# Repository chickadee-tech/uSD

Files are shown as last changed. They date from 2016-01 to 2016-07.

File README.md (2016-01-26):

# Chickadee Tech MicroSD Polystack Mod #
This mod adds a microSD card to a Polystack.

## Documentation ##
See the [wiki](https://github.com/chickadee-tech/uSD/wiki) for documentation.

## Polystack ##
This **mod** board is part of the Polystack platform for modular microcontrol systems. More information on the platform can be found at [polystack.org](http://polystack.org).

## Support ##
If you need support with a board you own or have development questions please email support@chickadee.tech or check [chickadee.tech/support](https://chickadee.tech/support) for other ways to get support.

## Contributing ##
Please note that this project is released with a [Contributor Code of Conduct](CODE_OF_CONDUCT.md). By participating in this project you agree to abide by its terms.

### Setup ###
Components and footprints for PCB parts are not included in this repository. Instead, checkout the [chickadee-tech/kicad-libs](https://github.com/chickadee-tech/kicad-libs) repository in the same directory that this repository is checked out in. All part definitions should be relative so that they will load correctly.

### Pull requests ###
For fixes please submit a pull request to the original repository. After the pull request is merged, check the [Chickadee Tech Active Contributor Discount (ACD)](https://chickadee.tech/active-contributor) to see if you are eligible for a discount code to use on your next purchase.

### Derivatives ###
If developing your own version of the MicroSD board please remove all Chickadee Tech trademarks and follow the [CC-BY license](LICENSE). While not required, please consider open sourcing your modifications so others can learn from your improvements. If you do email support@chickadee.tech and we may choose to add your project to the ACD.

You may also license the Polystack logo for free by emailing support@chickadee.tech. We'll ask for your gerbers to ensure the design complies with specifications laid out [here](https://github.com/chickadee-tech/polystack/wiki) and provide written permission to use the trademark after compliance has been demonstrated.

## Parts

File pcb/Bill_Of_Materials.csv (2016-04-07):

part name | symbol | size (imp) | max current | unit price | units per build | units in stock | order total | Manufacturer ID | source url | datasheet | datasheet2
80 pin header | PORT_IN1 |  |  | $1.35 | 1 | 1 | $1.35 | DF40C-80DP-0.4V(51) | http://www.digikey.com/product-detail/en/DF40C-80DP-0.4V(51)/H11632CT-ND/1969511 | N | http://www.hirose.co.jp/cataloge_hp/ed_DF40_20140305.pdf | Total Base Cost | $9.24
80 pin receptacle (3.5mm) | PORT_OUT1 |  | 0.3A a pin | $2.42 | 1 | 1 | $2.42 | DF40HC(3.5)-80DS-0.4V(51) | http://www.digikey.com/product-detail/en/DF40HC(3.5)-80DS-0.4V(51)/H11997CT-ND/2880228 | N | http://www.hirose.co.jp/cataloge_hp/ed_DF40_20140305.pdf
AND/OR gate | PORT_ANDOR1 |  |  | $0.25 | 1 | 2 | $0.25 | SN74LVC1G0832DCKR | http://www.digikey.com/product-detail/en/SN74LVC1G0832DCKR/296-18754-1-ND/863884 |  | http://www.ti.com/lit/ds/symlink/sn74lvc1g0832.pdf
multifunction gate | PORT_XOR1, PORT_INV1 |  |  | $0.14 | 2 | 6 | $0.28 | SN74LVC1G58DCKR | http://www.digikey.com/product-detail/en/SN74LVC1G58DCKR/296-15577-1-ND/571153 |  | http://www.ti.com/lit/ds/symlink/sn74lvc1g58.pdf
64kbit eeprom | PORT_IC1 | udfn |  | $0.61 | 1 | 2 | $0.61 | AT24CS64-MAHM-T | http://www.digikey.com/product-detail/en/AT24CS64-MAHM-T/AT24CS64-MAHM-TCT-ND/4292118 | N | http://www.atmel.com/images/atmel-8870-seeprom-at24cs64-datasheet.pdf
R 10k | PORT_R1, R3 | 603 |  | $0.01 | 2 | 979 | $0.02 | RC0603FR-0710KL | http://www.digikey.com/product-detail/en/RC0603FR-0710KL/311-10.0KHRCT-ND/729827 | MF-RES-0603-10K | http://www.yageo.com/NewPortal/yageodocoutput?fileName=/pdf/R-Chip/PYu-RC_Group_51_RoHS_L_3.pdf
C 0.1uF | PORT_C1 | 603 |  | $0.02 | 1 | 400 | $0.02 | C0603C104K4RACTU | http://www.digikey.com/product-detail/en/C0603C104K4RACTU/399-1096-1-ND/411371 | MF-CAP-0603-0.1uF | http://www.kemet.com/docfinder?Partnumber=C0603C104K4RACTU
R 1k | R1, R2 | 603 |  | $0.01 | 2 | 993 | $0.02 | RC0603FR-071KL | http://www.digikey.com/product-detail/en/RC0603FR-071KL/311-1.00KHRCT-ND/729790 | MF-RES-0603-1K | http://www.yageo.com/NewPortal/yageodocoutput?fileName=/pdf/R-Chip/PYu-RC_Group_51_RoHS_L_3.pdf
red led | D1 |  |  | $0.19 | 1 | 71 | $0.19 | LTST-C190KRKT | http://www.digikey.com/product-detail/en/LTST-C190KRKT/160-1436-1-ND/386816 | MF-LED-0603-RED | http://optoelectronics.liteon.com/upload/download/DS-22-99-0151/S_110_LTST-C190KRKT.pdf
green led | D2 |  |  | $0.19 | 1 | 83 | $0.19 | LTST-C190KGKT | http://www.digikey.com/product-detail/en/LTST-C190KGKT/160-1435-1-ND/386814 | Y | http://optoelectronics.liteon.com/upload/download/DS22-2000-074/S_110_LTST-C190KGKT.pdf
3.3v regulator | U1 | SOT23-5 | 0.3A | $0.49 | 1 | 8 | $0.49 | TLV70233DBVR | http://www.digikey.com/product-detail/en/TLV70233DBVR/296-32415-1-ND/3505572 | MF-REG-SOT235-3.3V-300mA | http://www.ti.com/lit/ds/symlink/tlv702.pdf
autoeject microsd | U2 |  |  | $2.72 | 1 | 1 | $2.72 | DM3AT-SF-PEJM5 | http://www.digikey.com/product-detail/en/DM3AT-SF-PEJM5/HR1964CT-ND/2533566 | N | http://www.hirose.co.jp/cataloge_hp/e60900232.pdf
C 10uF X5R | C1 | 1206 |  | $0.24 | 1 | 80 | $0.24 | C3216X5R1C106M160AA | http://www.digikey.com/product-detail/en/C3216X5R1C106M160AA/445-1426-1-ND/569092 | MF-CAP-1206-10uF | http://product.tdk.com/en/catalog/datasheets/mlcc_commercial_general_en.pdf
C 1uF X7R | C2 | 603 |  | $0.03 | 1 | 20 | $0.03 | TMK107B7105KA-T | http://www.digikey.com/product-detail/en/TMK107B7105KA-T/587-2984-1-ND/2714177 | MF-CAP-0603-1uF | http://ds.yuden.co.jp/TYCOMPAS/ut/detail.do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
~3.5mm Spacer | Off Board |  |  | $0.08 | 5 | 81 | $0.42 | 908-140 | http://www.mouser.com/search/ProductDetail.aspx?R=0virtualkey0virtualkey908-140 | N | http://www.bivar.com/Portals/0/Products/d.ashx?f=/Portals/0/products/9XX-XXX.pdf

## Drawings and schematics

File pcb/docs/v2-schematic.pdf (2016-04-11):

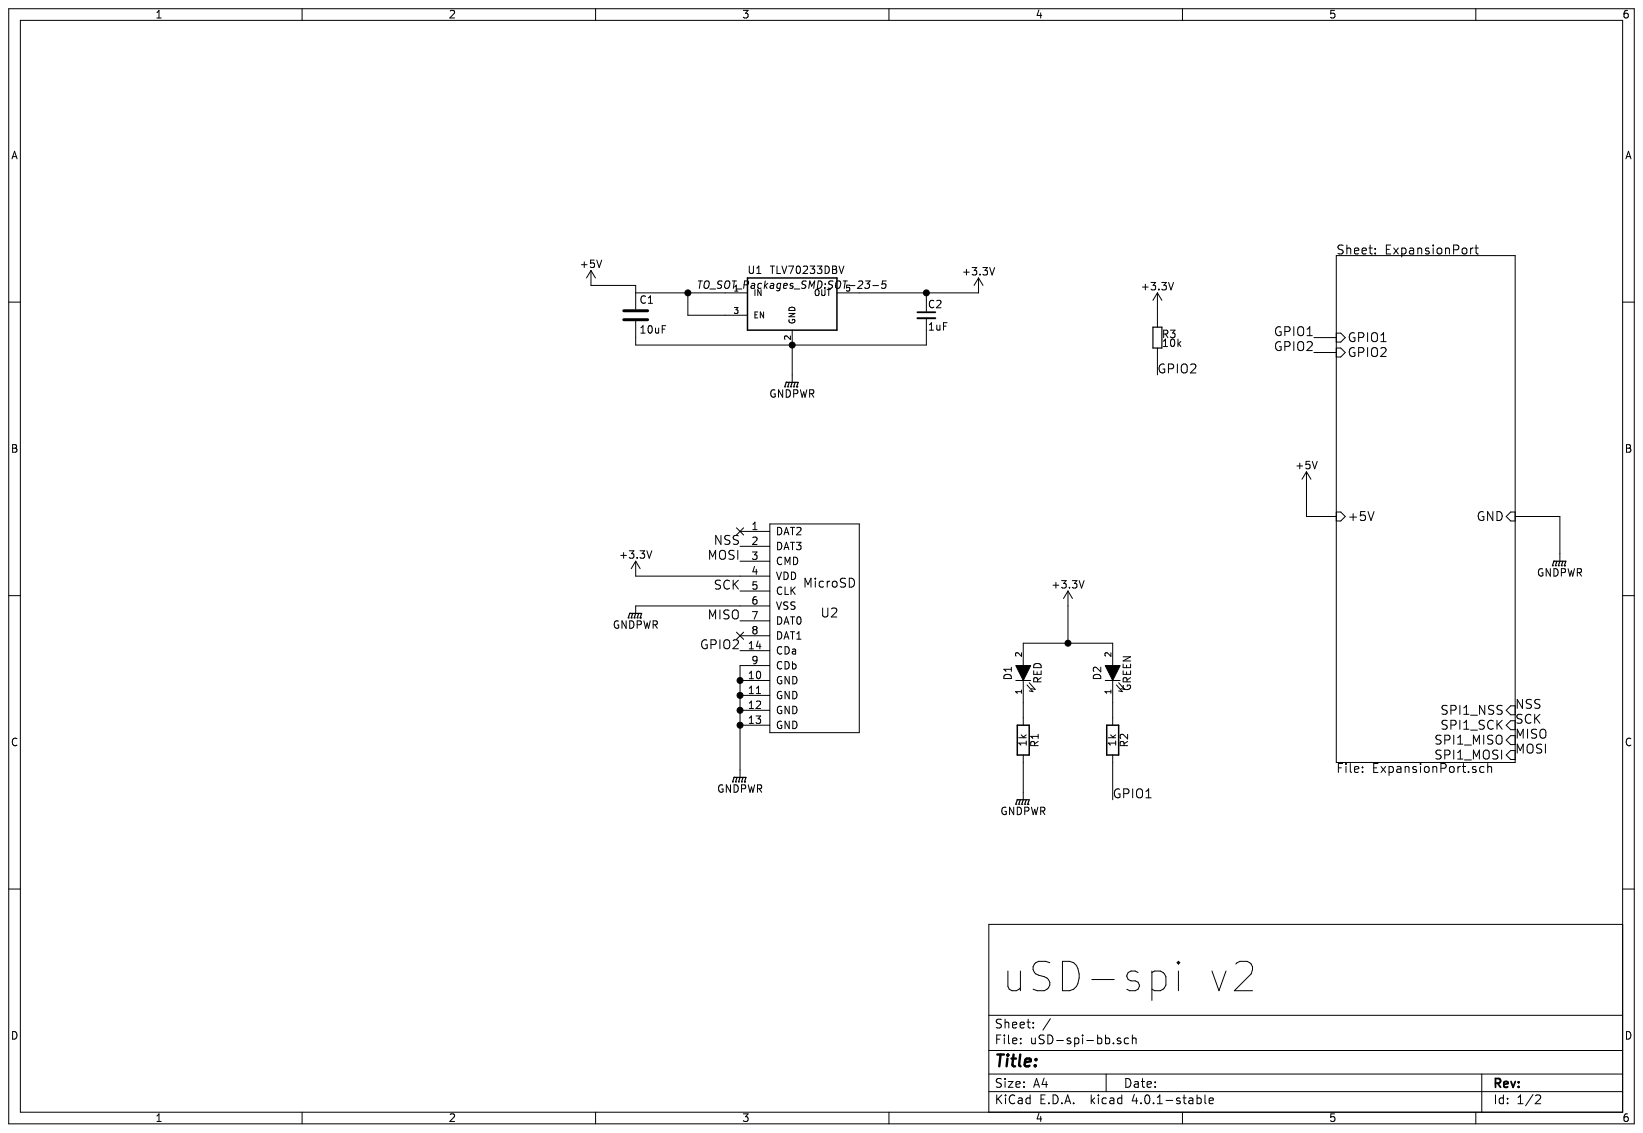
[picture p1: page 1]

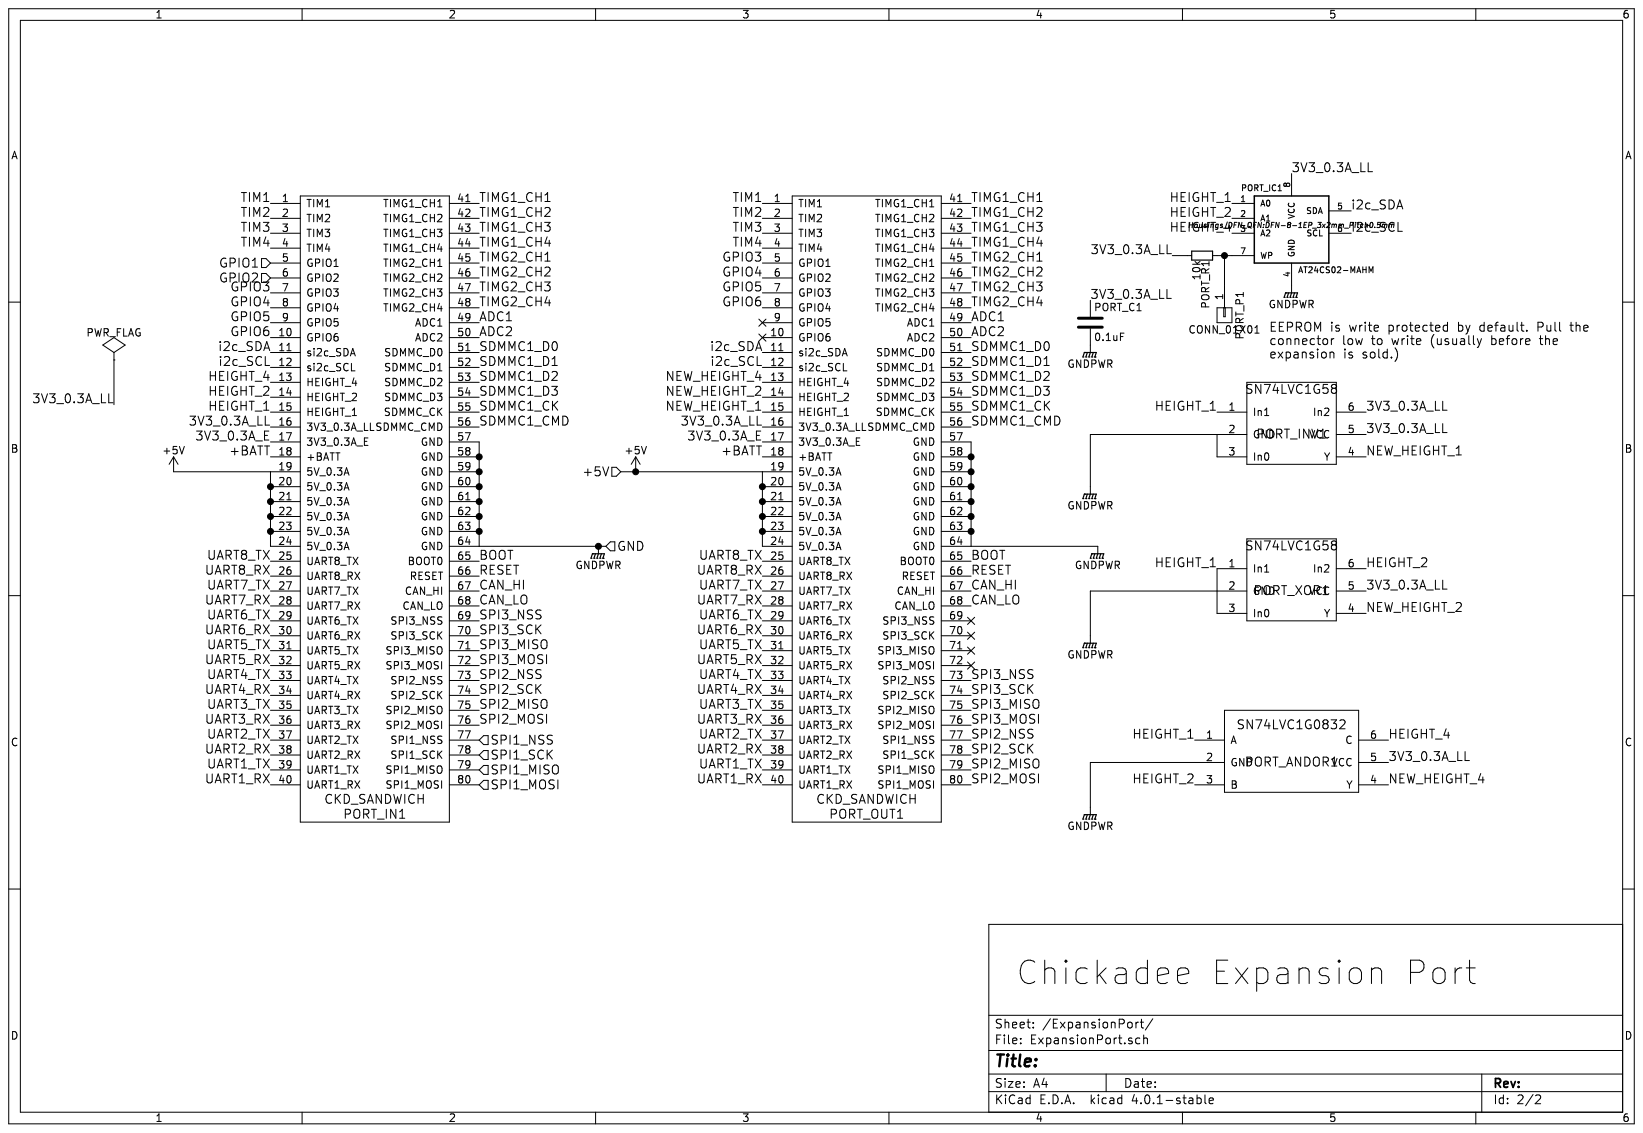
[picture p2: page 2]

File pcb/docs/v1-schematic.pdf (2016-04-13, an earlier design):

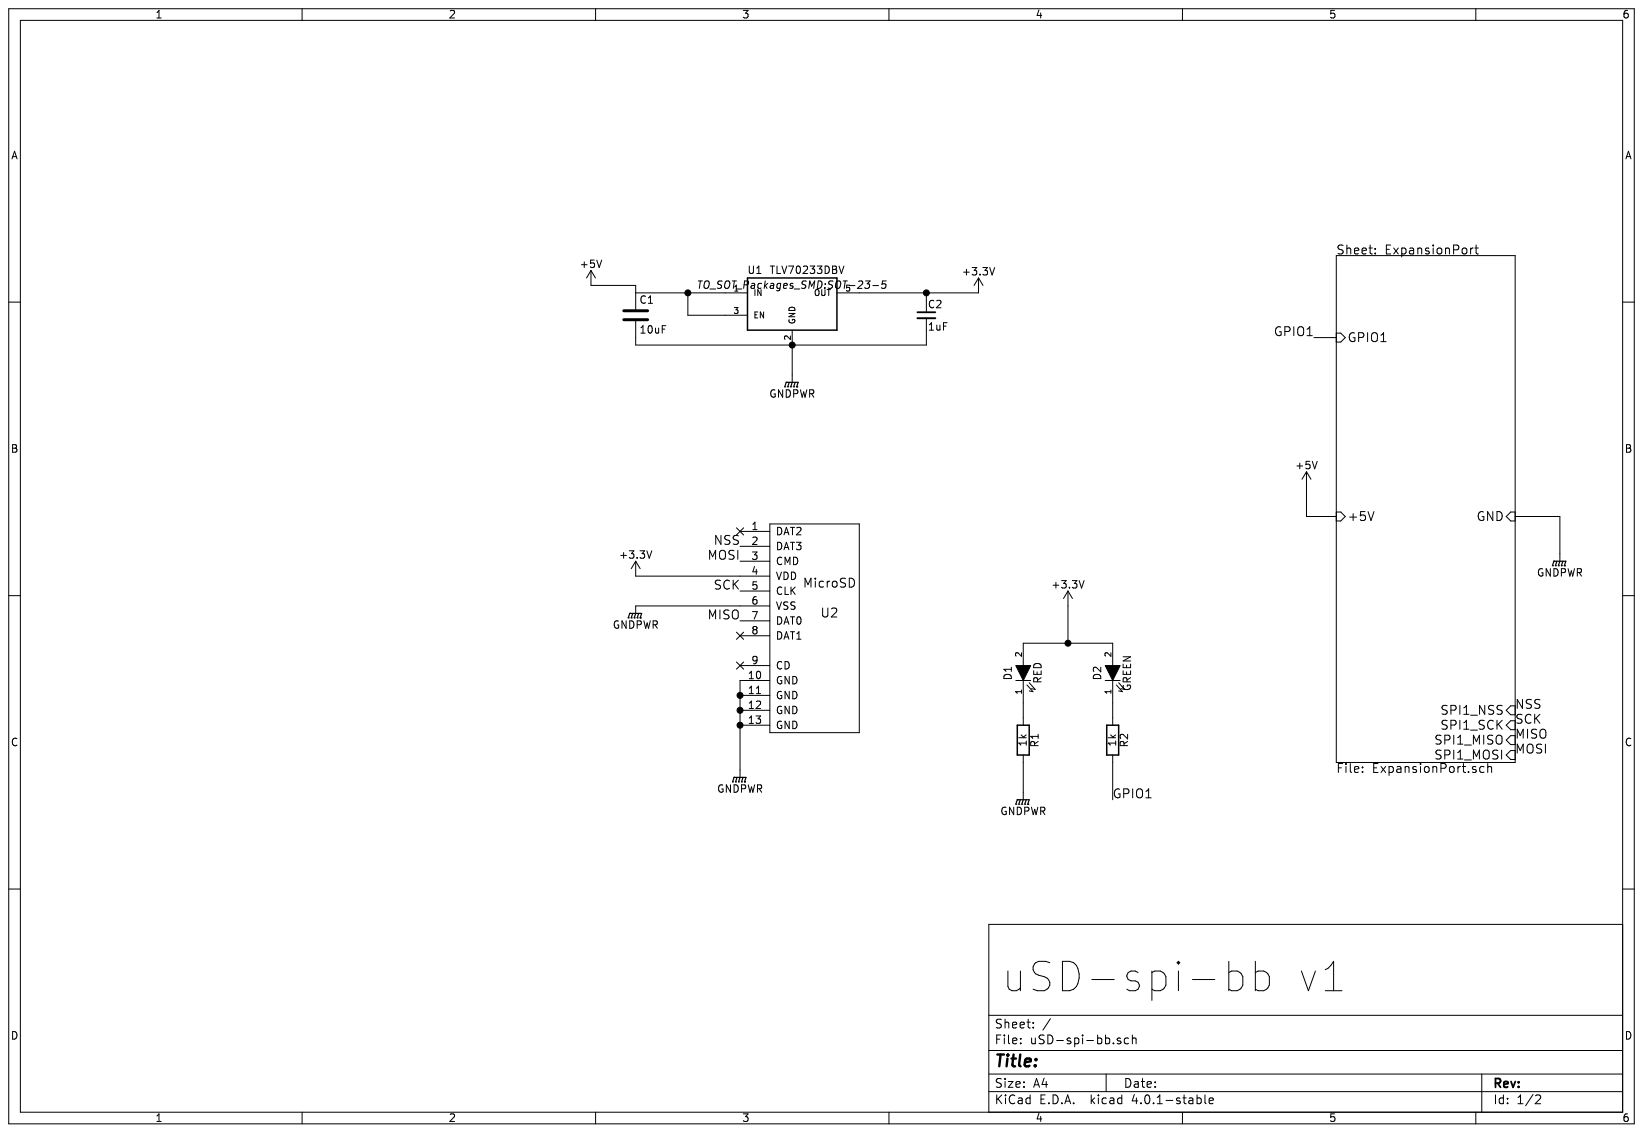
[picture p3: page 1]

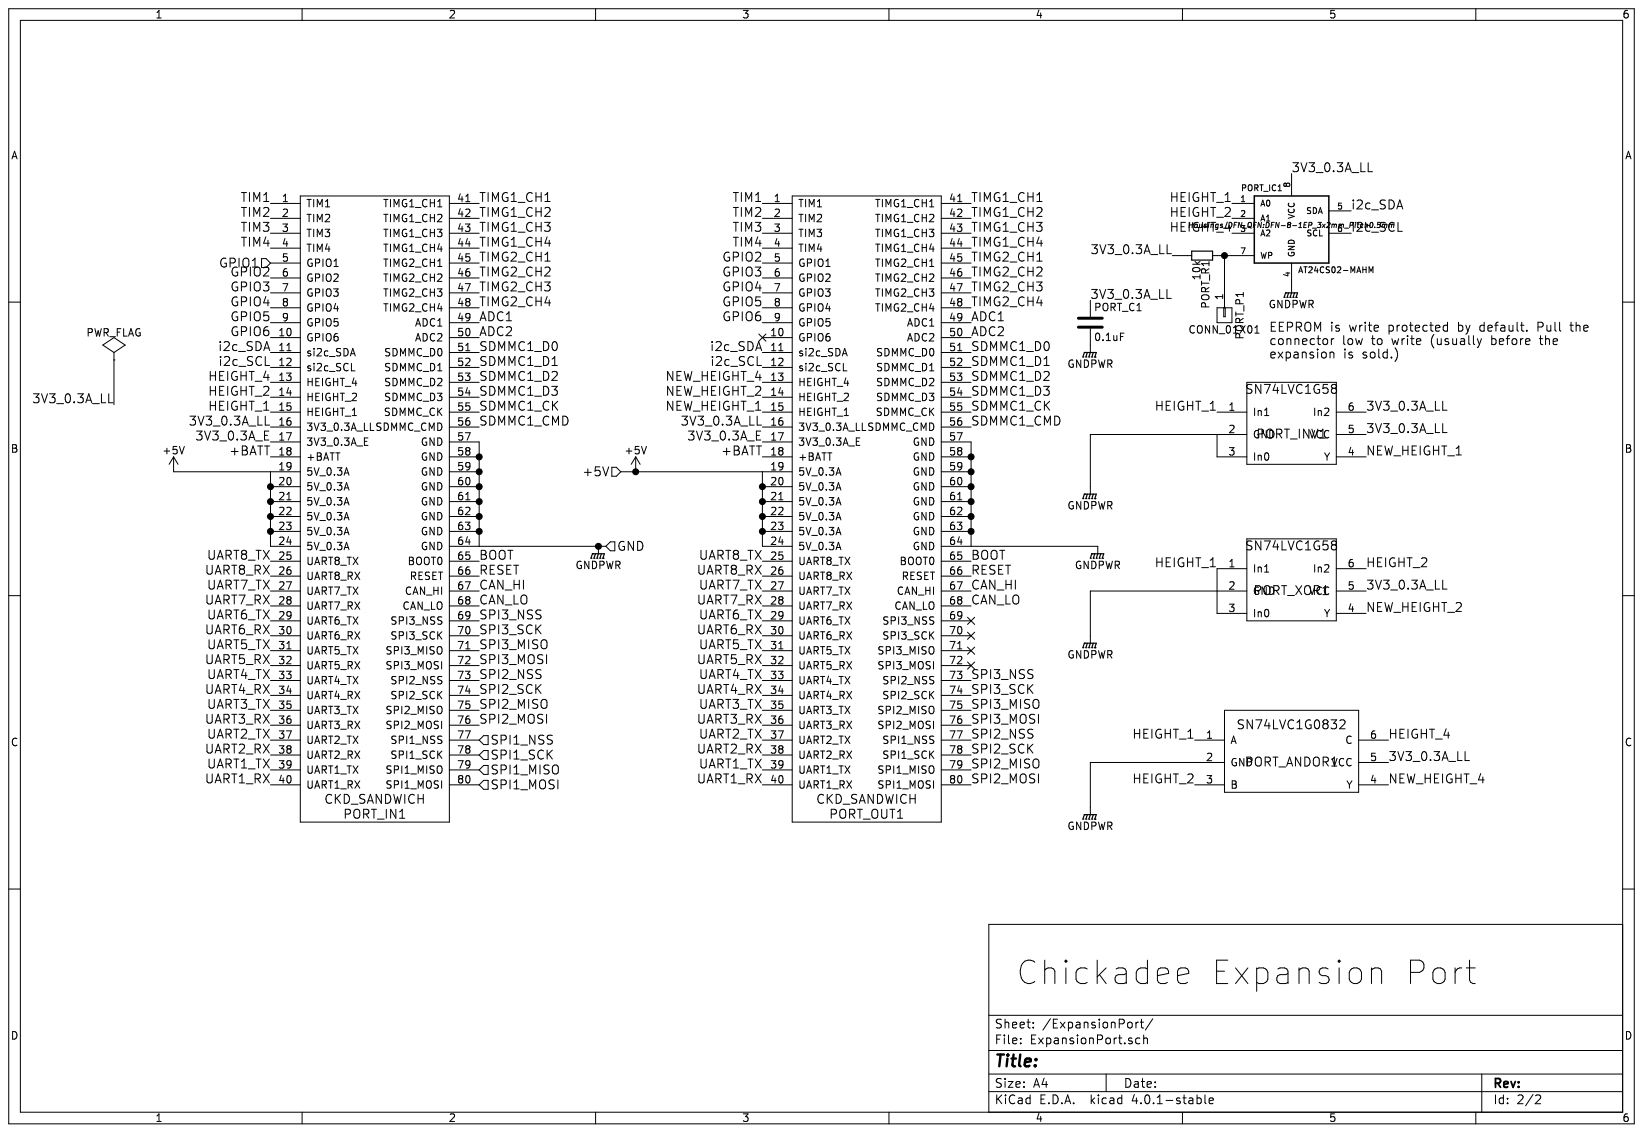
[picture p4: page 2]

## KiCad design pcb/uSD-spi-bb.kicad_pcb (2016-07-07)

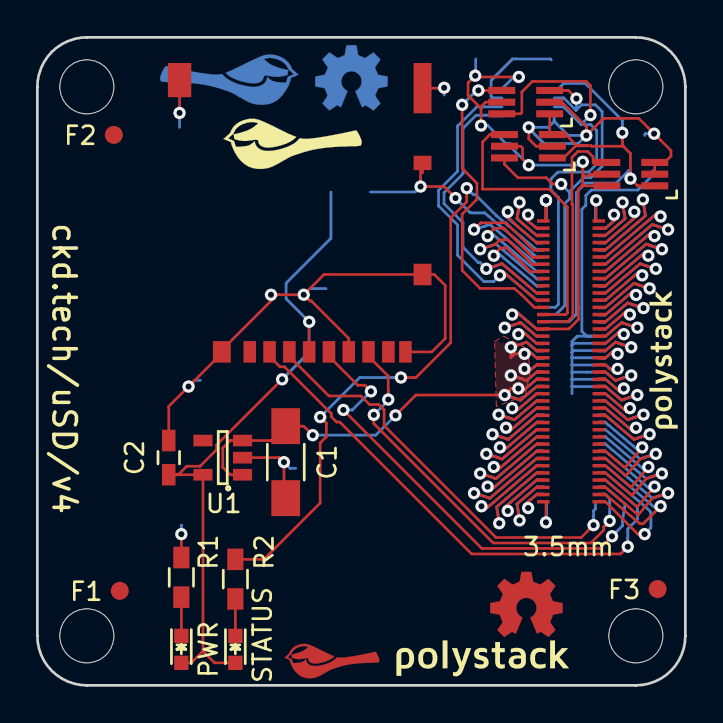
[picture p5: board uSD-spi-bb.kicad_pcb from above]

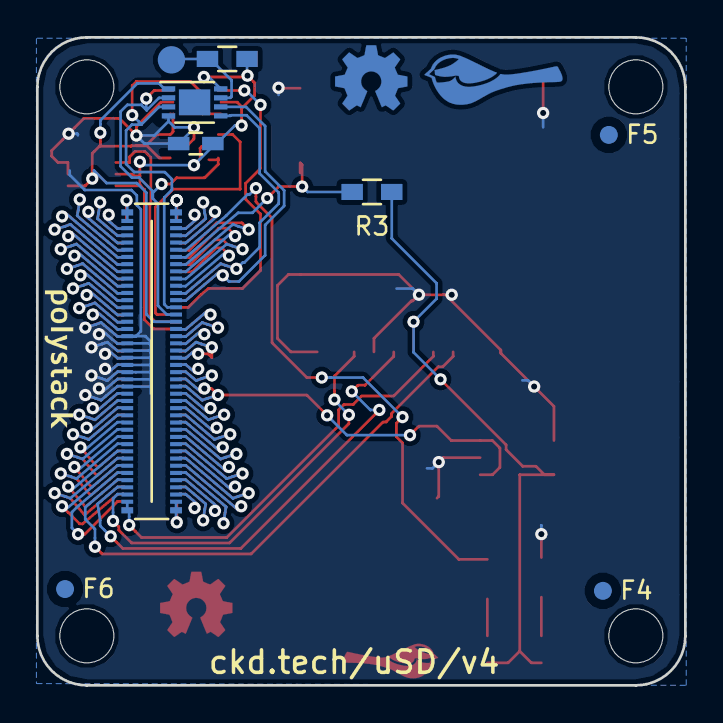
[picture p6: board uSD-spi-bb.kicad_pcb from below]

Board: 2 copper layers, 36.0 x 36.0 mm, 27 parts (10 on the bottom side), 75 nets.

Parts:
C1: 10uF; C_1206_HandSoldering
C2: 1uF; C_0603_HandSoldering
D1: RED; LED_0603
D2: GREEN; LED_0603
F1, F2, F3, F4, F5, F6: 1mm; Fiducial
PORT_ANDOR1: SN74LVC1G0832; SC-70-6_Handsoldering
PORT_C1: 0.1uF; C_0603_HandSoldering
PORT_IC1: AT24CS02-MAHM; DFN-8-1EP_3x2mm_Pitch0.5mm
PORT_IN1: CKD_SANDWICH; DF40-80pin-Header
PORT_INV1: SN74LVC1G58; SC-70-6_Handsoldering
PORT_OUT1: CKD_SANDWICH; DF40-3-4mm-80pin-Receptacle
PORT_P1: CONN_01X01; Measurement_Point_Round-SMD-Pad_Small
PORT_R1: 10k; R_0603_HandSoldering
PORT_XOR1: SN74LVC1G58; SC-70-6_Handsoldering
R1, R2: 1k; R_0603_HandSoldering
R3: 10k; R_0603_HandSoldering
U1: TLV70233DBV; SOT-23-5
U2: MicroSD; DM3AT
svg2mod: G***; polystack-bold-0.5
svg2mod#2, svg2mod#3: G***; polystack-bold-0.4

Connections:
+3V3: C2.1, D1.2, D2.2, R3.1, U1.5, U2.4
+5V: C1.1, PORT_IN1.19, PORT_IN1.20, PORT_IN1.21, PORT_IN1.22, PORT_IN1.23, PORT_IN1.24, PORT_OUT1.19, PORT_OUT1.20, PORT_OUT1.21, PORT_OUT1.22, PORT_OUT1.23, PORT_OUT1.24, U1.1, U1.3
/ExpansionPort/3V3_0.3A_E: PORT_IN1.17, PORT_OUT1.17
/ExpansionPort/3V3_0.3A_LL: PORT_ANDOR1.5, PORT_C1.1, PORT_IC1.8, PORT_IN1.16, PORT_INV1.5, PORT_INV1.6, PORT_OUT1.16, PORT_R1.2, PORT_XOR1.5
/ExpansionPort/+BATT: PORT_IN1.18, PORT_OUT1.18
/ExpansionPort/ADC1: PORT_IN1.49, PORT_OUT1.49
/ExpansionPort/ADC2: PORT_IN1.50, PORT_OUT1.50
/ExpansionPort/BOOT: PORT_IN1.65, PORT_OUT1.65
/ExpansionPort/CAN_HI: PORT_IN1.67, PORT_OUT1.67
/ExpansionPort/CAN_LO: PORT_IN1.68, PORT_OUT1.68
/ExpansionPort/GPIO1: PORT_IN1.5, R2.2
/ExpansionPort/GPIO2: PORT_IN1.6, R3.2, U2.14
/ExpansionPort/GPIO3: PORT_IN1.7, PORT_OUT1.5
/ExpansionPort/GPIO4: PORT_IN1.8, PORT_OUT1.6
/ExpansionPort/GPIO5: PORT_IN1.9, PORT_OUT1.7
/ExpansionPort/GPIO6: PORT_IN1.10, PORT_OUT1.8
/ExpansionPort/HEIGHT_1: PORT_ANDOR1.1, PORT_IC1.1, PORT_IN1.15, PORT_INV1.1, PORT_XOR1.1, PORT_XOR1.3
/ExpansionPort/HEIGHT_2: PORT_ANDOR1.3, PORT_IC1.2, PORT_IN1.14, PORT_XOR1.6
/ExpansionPort/HEIGHT_4: PORT_ANDOR1.6, PORT_IC1.3, PORT_IN1.13
/ExpansionPort/NEW_HEIGHT_1: PORT_INV1.4, PORT_OUT1.15
/ExpansionPort/NEW_HEIGHT_2: PORT_OUT1.14, PORT_XOR1.4
/ExpansionPort/NEW_HEIGHT_4: PORT_ANDOR1.4, PORT_OUT1.13
/ExpansionPort/RESET: PORT_IN1.66, PORT_OUT1.66
/ExpansionPort/SDMMC1_CK: PORT_IN1.55, PORT_OUT1.55
/ExpansionPort/SDMMC1_CMD: PORT_IN1.56, PORT_OUT1.56
/ExpansionPort/SDMMC1_D0: PORT_IN1.51, PORT_OUT1.51
/ExpansionPort/SDMMC1_D1: PORT_IN1.52, PORT_OUT1.52
/ExpansionPort/SDMMC1_D2: PORT_IN1.53, PORT_OUT1.53
/ExpansionPort/SDMMC1_D3: PORT_IN1.54, PORT_OUT1.54
/ExpansionPort/SPI1_MISO: PORT_IN1.79, U2.7
/ExpansionPort/SPI1_MOSI: PORT_IN1.80, U2.3
/ExpansionPort/SPI1_NSS: PORT_IN1.77, U2.2
/ExpansionPort/SPI1_SCK: PORT_IN1.78, U2.5
/ExpansionPort/SPI2_MISO: PORT_IN1.75, PORT_OUT1.79
/ExpansionPort/SPI2_MOSI: PORT_IN1.76, PORT_OUT1.80
/ExpansionPort/SPI2_NSS: PORT_IN1.73, PORT_OUT1.77
/ExpansionPort/SPI2_SCK: PORT_IN1.74, PORT_OUT1.78
/ExpansionPort/SPI3_MISO: PORT_IN1.71, PORT_OUT1.75
/ExpansionPort/SPI3_MOSI: PORT_IN1.72, PORT_OUT1.76
/ExpansionPort/SPI3_NSS: PORT_IN1.69, PORT_OUT1.73
/ExpansionPort/SPI3_SCK: PORT_IN1.70, PORT_OUT1.74
/ExpansionPort/TIM1: PORT_IN1.1, PORT_OUT1.1
/ExpansionPort/TIM2: PORT_IN1.2, PORT_OUT1.2
/ExpansionPort/TIM3: PORT_IN1.3, PORT_OUT1.3
/ExpansionPort/TIM4: PORT_IN1.4, PORT_OUT1.4
/ExpansionPort/TIMG1_CH1: PORT_IN1.41, PORT_OUT1.41
/ExpansionPort/TIMG1_CH2: PORT_IN1.42, PORT_OUT1.42
/ExpansionPort/TIMG1_CH3: PORT_IN1.43, PORT_OUT1.43
/ExpansionPort/TIMG1_CH4: PORT_IN1.44, PORT_OUT1.44
/ExpansionPort/TIMG2_CH1: PORT_IN1.45, PORT_OUT1.45
/ExpansionPort/TIMG2_CH2: PORT_IN1.46, PORT_OUT1.46
/ExpansionPort/TIMG2_CH3: PORT_IN1.47, PORT_OUT1.47
/ExpansionPort/TIMG2_CH4: PORT_IN1.48, PORT_OUT1.48
/ExpansionPort/UART1_RX: PORT_IN1.40, PORT_OUT1.40
/ExpansionPort/UART1_TX: PORT_IN1.39, PORT_OUT1.39
/ExpansionPort/UART2_RX: PORT_IN1.38, PORT_OUT1.38
/ExpansionPort/UART2_TX: PORT_IN1.37, PORT_OUT1.37
/ExpansionPort/UART3_RX: PORT_IN1.36, PORT_OUT1.36
/ExpansionPort/UART3_TX: PORT_IN1.35, PORT_OUT1.35
/ExpansionPort/UART4_RX: PORT_IN1.34, PORT_OUT1.34
/ExpansionPort/UART4_TX: PORT_IN1.33, PORT_OUT1.33
/ExpansionPort/UART5_RX: PORT_IN1.32, PORT_OUT1.32
/ExpansionPort/UART5_TX: PORT_IN1.31, PORT_OUT1.31
/ExpansionPort/UART6_RX: PORT_IN1.30, PORT_OUT1.30
/ExpansionPort/UART6_TX: PORT_IN1.29, PORT_OUT1.29
/ExpansionPort/UART7_RX: PORT_IN1.28, PORT_OUT1.28
/ExpansionPort/UART7_TX: PORT_IN1.27, PORT_OUT1.27
/ExpansionPort/UART8_RX: PORT_IN1.26, PORT_OUT1.26
/ExpansionPort/UART8_TX: PORT_IN1.25, PORT_OUT1.25
/ExpansionPort/i2c_SCL: PORT_IC1.6, PORT_IN1.12, PORT_OUT1.12
/ExpansionPort/i2c_SDA: PORT_IC1.5, PORT_IN1.11, PORT_OUT1.11
GNDPWR: C1.2, C2.2, PORT_ANDOR1.2, PORT_C1.2, PORT_IC1.4, PORT_IN1.57, PORT_IN1.58, PORT_IN1.59, PORT_IN1.60, PORT_IN1.61, PORT_IN1.62, PORT_IN1.63, PORT_IN1.64, PORT_INV1.2, PORT_INV1.3, PORT_OUT1.57, PORT_OUT1.58, PORT_OUT1.59, PORT_OUT1.60, PORT_OUT1.61, PORT_OUT1.62, PORT_OUT1.63, PORT_OUT1.64, PORT_XOR1.2, R1.2, U1.2, U2.6, U2.9, U2.10, U2.11, U2.12, U2.13
unnamed: D1.1, R1.1
unnamed: D2.1, R2.1
unnamed: PORT_IC1.7, PORT_P1.1, PORT_R1.1

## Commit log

2016-01-26 BlackBox logger that writes directly to a microSD card over SPI.
    [Bill_Of_Materials.csv, ExpansionPort.sch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]
2016-04-07 Add card detect to uSD BB.
    [Bill_Of_Materials.csv, ExpansionPort.sch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]
2016-04-11 Correct schematic label and save PDF of schematic for easy reference.
    [uSD-spi-bb.sch]
2016-04-13 Rebrand everything to Polystack and increment versions.
    [uSD-spi-bb.kicad_pcb]
2016-04-16 Final gerbers for test manufacturing run.
    [uSD-spi-bb-B.Cu.gbl, uSD-spi-bb-B.Mask.gbs, uSD-spi-bb-B.Paste.gbp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]
2016-06-07 Update polystack logo to bold variant, remove 'bb' from url and bump version number.
    [uSD-spi-bb.kicad_pcb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]
2016-07-07 Add license information to many files. PCB design files are CC-BY and code is MIT license.
    [ExpansionPort.sch, uSD-spi-bb.kicad_pcb, uSD-spi-bb.sch]
2016-07-07 Convert to relative component and footprint paths.
    [ExpansionPort.sch]
2016-07-09 Switch to polystack lib.
    [uSD-spi-bb.sch]

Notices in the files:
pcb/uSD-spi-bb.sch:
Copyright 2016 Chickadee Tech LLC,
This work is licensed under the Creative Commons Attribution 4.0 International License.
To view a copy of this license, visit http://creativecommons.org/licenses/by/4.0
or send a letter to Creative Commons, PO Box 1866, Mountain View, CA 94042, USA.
